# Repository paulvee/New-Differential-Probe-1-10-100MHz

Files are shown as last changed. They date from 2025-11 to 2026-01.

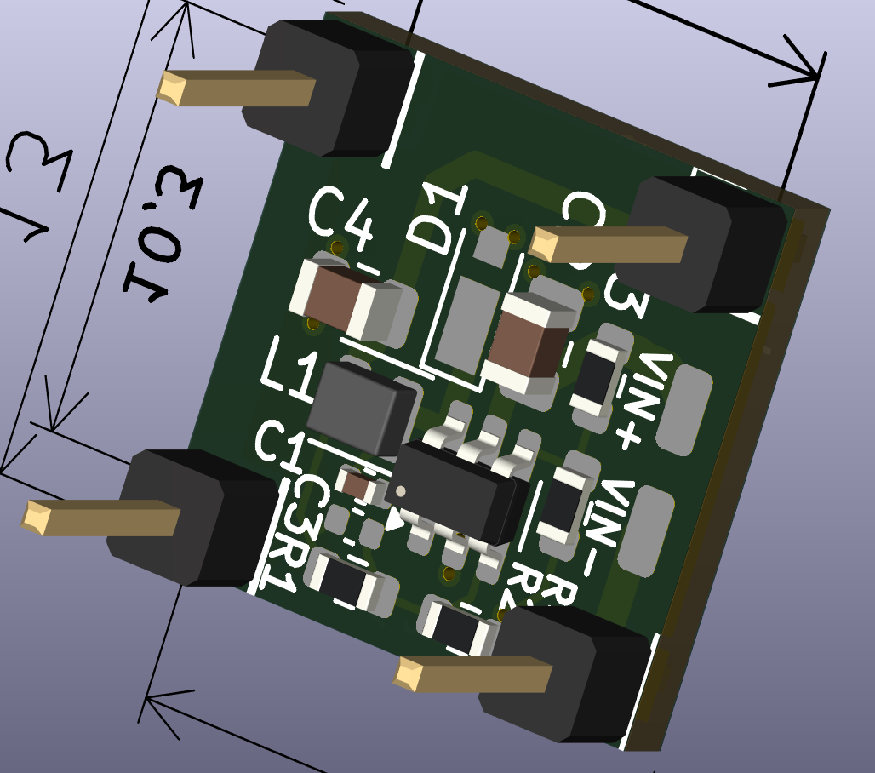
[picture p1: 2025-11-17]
VREG-BUCK-DB/3D profile.png

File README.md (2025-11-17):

This is a project to build a DIY differential probe for oscilloscopes (CRT or DSO)
This project was based on an earlier version of a few years ago and went through a number of enhancements based on what we learned.

There are now three versions of the probe, a 1MHz, a 10MHz and a 100MHz version, using the same PCB, but with different parts.
These three versions can be powered by a number of so called voltage regulator Daughter Boards.
Two are listed here. They can be powered by USB-C PD Trigger Boards. 

There is also a 3D printed version of the probe enclosure available.
The files in this project folder contain the schematics, the BOM and the production information to order the PCB's and enclosure.
All other information about this project can be found on my Blog here:
https://www.paulvdiyblogs.net/2025/08/building-new-100mhz-differential-probe.html

The specifications for the 100MHz probe are: (the others are on the Blog)
- Input impedance: 20MegOhm//1.25pF - differential, 10MegOhm//2.5pF for each terminal to GND.
- Differential Gain = 1/10V/V. Any lower than this and most hobby DSO's cannot resolve a 1V input signal with any clarity.
- Maximum AC Common Mode Voltage (with 50V differential input) = 350VAC
- CMRR > 90dB @ DC, ~60dB @ 1MHz.
- Differential Voltage Range > +/-25V for 240VAC common-mode, +/-25V for 0V common-mode.
- 3dB bandwidth >= 100MHZ (depends on signal amplitude)
- DC offset < 1mV (trimmed)
- Noise: 30mVpp or lower at output.
- Power supply: 5.25V +/- 0.25V. This can be a USB-C PD supply plus a regulator, see the power options.
- Cost: ~$50 not including shipping and handling costs. Not including 3D printed enclosure.

Enjoy building one of these, you will be happy that you did!

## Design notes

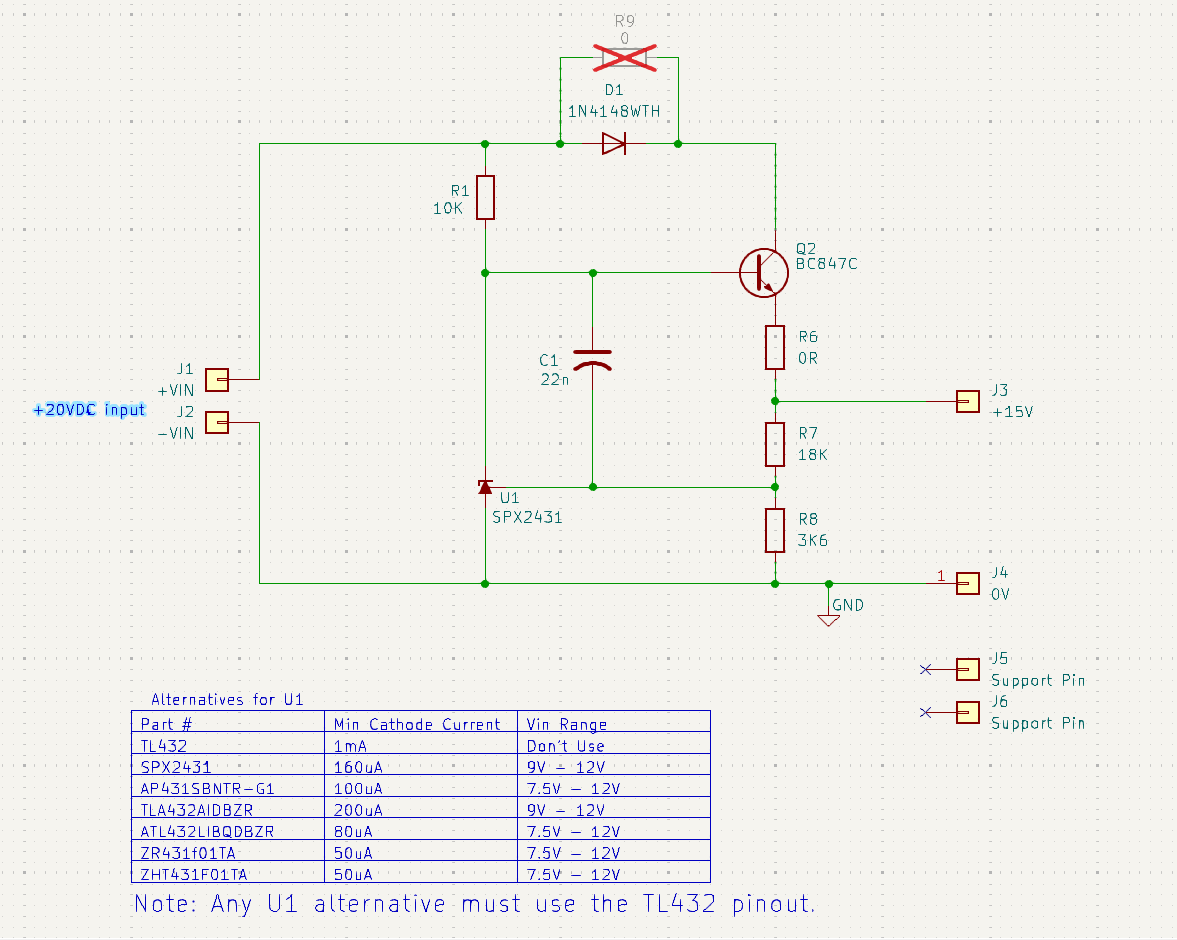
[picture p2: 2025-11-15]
VREG-DISCRETE-DB/Schematic 20V.png

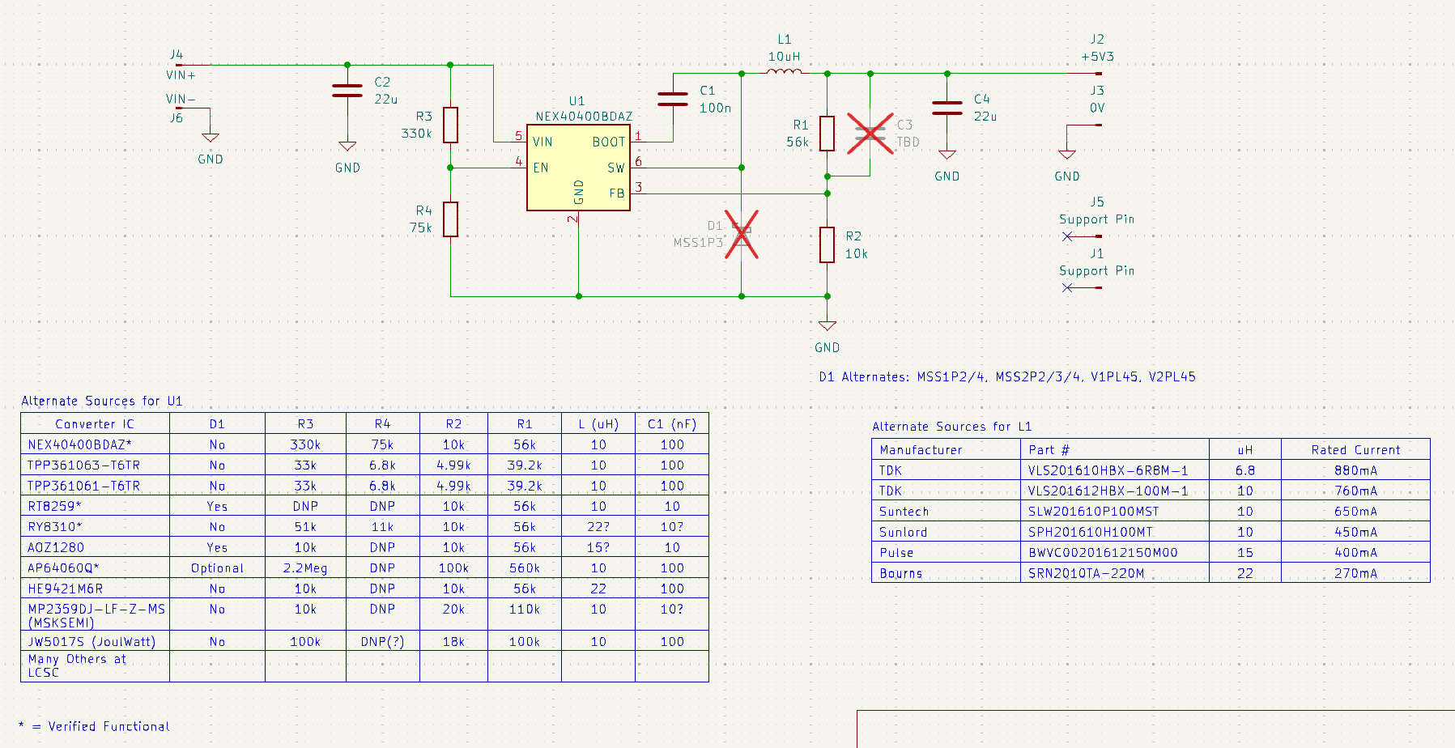
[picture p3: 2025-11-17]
VREG-BUCK-DB/Schematic.png

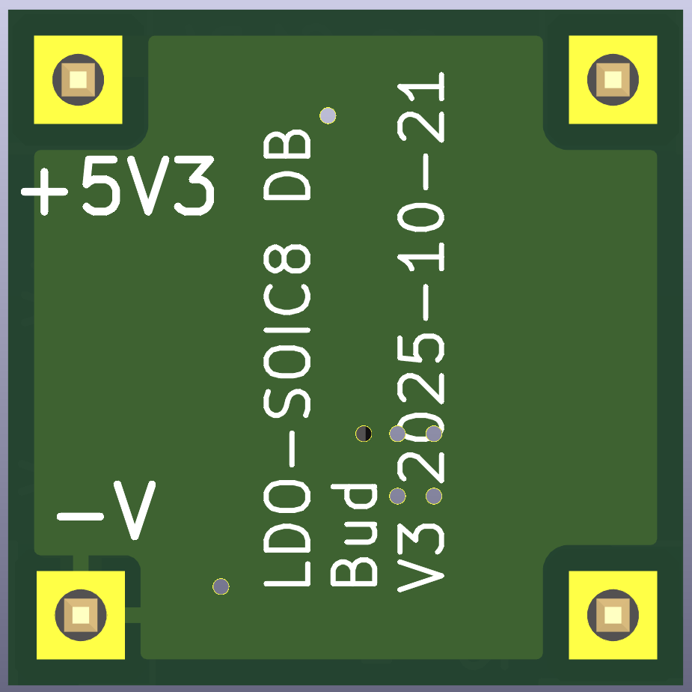
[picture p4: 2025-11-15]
VREG-SOIC8_DB/VREG-SOIC 3D top view.png

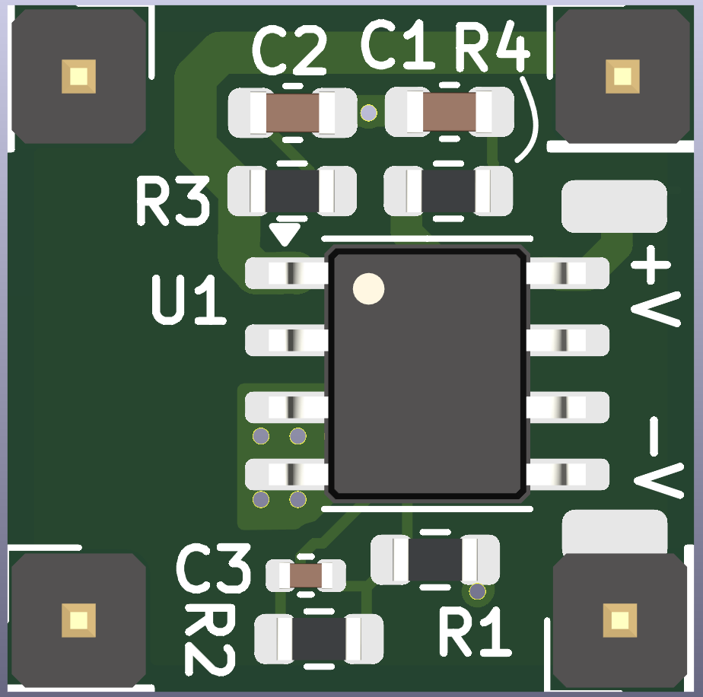
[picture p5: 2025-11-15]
VREG-SOIC8_DB/VREG-SOIC 3D view.png

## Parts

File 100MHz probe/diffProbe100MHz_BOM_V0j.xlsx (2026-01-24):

Reference | Value | Qty | Footprint | tempco | tolerance | Voltage | Source | Digikey Part # | LCSC Part # | LCSC Info
C1,C2,C3,C4,C5,C6,C7,C8 | 10p | 8 | Capacitor_SMD:C_0603_1608Metric | NPO | 1% | >200 | https://www.digikey.com/en/products/detail/kyocera-avx/KGQ15ACG2D100FT/1598981 | 478-KGQ15ACG2D100FTCT-ND | C2312027 | Double check the tolerance!
C9,C10 | 300p | 2 | Capacitor_SMD:C_0805_2012Metric | NPO | 1% | 50 | https://www.digikey.com/en/products/detail/kyocera-avx/08051A301FAT2A/1601047 | 478-10392-1-ND | C541567 | Double check the tolerance!
C11,C12 | 47p | 2 | Capacitor_SMD:C_0603_1608Metric | COG/NPO | 2% | 50 | https://www.digikey.com/en/products/detail/murata-electronics/GRM1885C1H470GA01D/2611190 | 490-11464-1-ND | C384994
C13,C14 | 220p | 2 | Capacitor_SMD:C_0805_2012Metric | COG/NPO | 1% | 50 | https://www.digikey.com/en/products/detail/yageo/CC0805FRNPO9BN221/5883936 | 311-4172-1-ND | C541563 | Double check the tolerance!
C15,C16 | 8-29p | 2 | My_Footprints:C_Trimmer_Voltronics_JR |  |  | 100 | https://www.digikey.com/en/products/detail/ew-electronics/sgc3s300/11689272 | 2447-SGC3S300CT-ND | C3273429 | Out of stock
C17,C18 *) | 0.2p | 2 | Capacitor_SMD:C_0402_1005Metric | COG/NPO | ±0.05p | 50 | https://www.digikey.com/en/products/detail/GJM1555C1HR20WB01D/490-11247-1-ND/5333087?itemSeq=313716339 | 490-11247-1-ND | Do not buy, they have a tolerance of 20%
C19,C21 *) | 0.4p | 2 | Capacitor_SMD:C_0402_1005Metric | COG/NPO | ±0.05p | 50 | https://www.digikey.com/en/products/detail/murata-electronics/GCM1555C1HR40WA16D/16033471 | 490-GCM1555C1HR40WA16DCT-ND | Do not buy, they have a tolerance of 20%
C20,C24,C26,C28 | 100p | 4 | Capacitor_SMD:C_0402_1005Metric | COG/NPO | 5% | 50 | https://www.digikey.com/en/products/detail/samsung-electro-mechanics/CL05C101JB5NNNC/3886683 | 1276-1025-1-ND | C1546 | Double check the tolerance!
C22,C25,C27,C29,C31 | 100n | 5 | Capacitor_SMD:C_0402_1005Metric | X7R | 10% | 50 | https://www.digikey.com/en/products/detail/kyocera-avx/KGM05CR71H104KH/6564238 | 478-KGM05CR71H104KHCT-ND | C307331
C23,C30,C36 | 4.7u | 3 | Capacitor_SMD:C_0603_1608Metric | X5R | 10% | 25 | https://www.digikey.com/en/products/detail/murata-electronics/GRM188R61E475KE11D/3900465 | 490-7203-1-ND | C69335
C32,C34 | 1u | 2 | Capacitor_SMD:C_0402_1005Metric | X5R | 10% | 16 | https://www.digikey.com/en/products/detail/murata-electronics/GRM155R61H105KE05D/13531808 | 490-GRM155R61H105KE05DCT-ND | C52923
C33,C35 | 10u | 2 | Capacitor_SMD:C_0603_1608Metric | X5R | 20% | 10 | https://www.digikey.nl/nl/products/detail/samsung-electro-mechanics/CL10A106KP8NNNC/3886850 | 1276-1192-1-ND | C19702
D1,D2 | BAV199 | 2 | Package_TO_SOT_SMD:SOT-23W |  |  |  | https://www.digikey.com/en/products/detail/diotec-semiconductor/BAV199/13164606 | 4878-BAV199CT-ND | C40919
D3 | LED | 1 | LED_SMD:LED_0603_1608Metric |  |  |  | https://www.digikey.nl/en/products/detail/harvatek-corporation/B19Y1TX-20P001713U1930/16602932? | 3147-B19Y1TX--20P001713U1930CT-ND | C2290
FB1,FB2 | FerriteBead | 2 | Inductor_SMD:L_0603_1608Metric |  | 1k@100MHz |  | https://www.digikey.com/en/products/detail/MPZ1608S102ATA00/445-8694-1-ND/3078632?itemSeq=313936277 | 445-MPZ1608S102ATA00CT-ND | C76814
J1 | SMA | 1 | Connector_Coaxial:SMA_Samtec_SMA-J-P-H-ST-EM1_EdgeMount |  |  |  | https://www.digikey.com/en/products/detail/samtec-inc/SMA-J-P-H-ST-EM1/2602450 | SAM8857-ND | C496550
J2 | 5.08 mm spacing pin header | 1 | My_Footprints:PinHeader_1x03_P2.54mm_Horizontal |  |  |  | https://www.digikey.nl/nl/products/detail/adam-tech/PH1RB-03-UA/9830403 | 2057-PH1RB-03-UA-ND | C3335189
J3 | -V | 1 | Connector_PinHeader_2.54mm:PinHeader_1x01_P2.54mm_Vertical |  |  |  | https://www.digikey.nl/nl/products/detail/adam-tech/PH1-01-UA/9830231 | 2057-PH1-01-UA-ND | C2932699
J4 | +V | 1 | Connector_PinHeader_2.54mm:PinHeader_1x01_P2.54mm_Vertical |  |  |  | https://www.digikey.nl/nl/products/detail/adam-tech/PH1-01-UA/9830231 | 2057-PH1-01-UA-ND | C2932699
J5,J6 | Support Pin | 2 | My_Footprints:TestPoint_THTPad_2.0x2.0mm_Drill1.0mm |  |  |  | https://www.digikey.nl/nl/products/detail/adam-tech/PH1-01-UA/9830232 | 2057-PH1-01-UA-ND | C2932699
R1,R2,R3,R4,R5,R6,R7,R8 | 2.49Meg | 8 | Resistor_SMD:R_0805_2012Metric |  | 1% | 150 | https://www.digikey.com/en/products/detail/yageo/RC0805FR-072M49L/727696 | 311-2.49MCRCT-ND | C83497 | Out of stock
R9,R11 | 36k | 2 | Resistor_SMD:R_0603_1608Metric |  | 1% |  | https://www.digikey.com/en/products/detail/koa-speer-electronics-inc/RN73H1JTTD3602F50/10674635 | 2019-RN73H1JTTD3602F50CT-ND | C136964
R10,R12 | 3k | 2 | Resistor_SMD:R_0603_1608Metric |  | 1% |  | https://www.digikey.com/en/products/detail/koa-speer-electronics-inc/RN73H1JTTD3001F100/10687131 | 2019-RN73H1JTTD3001F100CT-ND | C4211
R13,R14 | 1.5k | 2 | Resistor_SMD:R_0603_1608Metric |  | 1% |  | https://www.digikey.com/en/products/detail/koa-speer-electronics-inc/RN73H1JTTD1501F25/10686103 | 2019-RN73H1JTTD1501F25CT-ND | C114668
R15 | 412Ω | 1 | Resistor_SMD:R_0603_1608Metric |  | 1% |  | https://www.digikey.com/en/products/detail/yageo/RC0603FR-07412RL/727226 | 311-412HRCT-ND | C218022
R16,R17 | 3.92k | 2 | Resistor_SMD:R_0603_1608Metric |  | 1% |  | https://www.digikey.com/en/products/detail/yageo/RC0603FR-073K92L/727138 | RC0603FR-073K92L | C2933215
R18,R19 | 1.02k | 2 | Resistor_SMD:R_0603_1608Metric | 25ppm/C | 0.1% |  | https://www.digikey.nl/en/products/detail/yageo/RT0603BRD071K02L/1072313 | YAG2308CT-ND | C705734
R20,R21 | 1.27k | 2 | Resistor_SMD:R_0603_1608Metric | 25ppm/C | 0.1% |  | https://www.digikey.nl/en/products/detail/yageo/RT0603BRD071K27L/1072322 | YAG4492CT-ND | C855682
R22 | 51Ω | 1 | Resistor_SMD:R_0603_1608Metric |  | 1% |  | https://www.digikey.com/en/products/detail/yageo/RC0603FR-0751RL/727281 | 311-51.0HRCT-ND | C23197
R23 | 2.4k | 1 | Resistor_SMD:R_0603_1608Metric |  | 1% |  | https://www.digikey.com/en/products/detail/yageo/RC0603FR-132K4L/14008351 | 13-RC0603FR-132K4LCT-ND | C22940
R24,R29 | 10Ω | 2 | Resistor_SMD:R_0603_1608Metric |  | 1% |  | https://www.digikey.com/en/products/detail/yageo/RC0603FR-0710RL/726879 | 311-10.0HRCT-ND | C22859
R25,R28 | 510Ω | 2 | Resistor_SMD:R_0603_1608Metric |  | 1% |  | https://www.digikey.com/en/products/detail/yageo/RC0603FR-07510RL/727285 | 311-510HRCT-ND | C23193
R26,R27 | 10k | 2 | Resistor_SMD:R_0603_1608Metric |  | 1% |  | https://www.digikey.com/en/products/detail/yageo/RT0603FRE0710KL/1075040 | YAG2321CT-ND | C25804
R30,R31 | 1Ω | 2 | Resistor_SMD:R_0603_1608Metric |  | 5% |  | https://www.digikey.com/en/products/detail/yageo/RC0603JR-071RL/726676 | 311-1.0GRCT-ND | C22936
R32 | 3Ω | 1 | Resistor_SMD:R_0603_1608Metric |  | 5% |  | https://www.digikey.com/en/products/detail/yageo/RC0603JR-073RL/726753 | 311-3.0GRCT-ND | C23157
RV1,RV2 | 2k | 2 | Potentiometer_SMD:Potentiometer_Bourns_3224J_Horizontal |  | 20% |  | https://www.digikey.com/en/products/detail/bourns-inc/TC33X-2-202E/612860 | TC33X-202ECT-ND | C720647
U1 | LTC6269xMS8E-10 | 1 | Package_SO:MSOP-8-1EP_3x3mm_P0.65mm_EP1.68x1.88mm |  |  |  | https://www.digikey.com/en/products/detail/analog-devices-inc/LTC6269IMS8E-10-PBF/5253547 | 505-LTC6269IMS8E-10#PBF-ND | C689183
U2 | LTC6268xS6 | 1 | Package_TO_SOT_SMD:TSOT-23-6 |  |  |  | https://www.digikey.com/en/products/detail/analog-devices-inc/LTC6268IS6-TRMPBF/5030349 | 505-LTC6268IS6#TRMPBFCT-ND | C580981
U4 | LM7301DBV | 1 | Package_TO_SOT_SMD:SOT-23-5 |  |  |  | https://www.digikey.com/en/products/detail/texas-instruments/LM7301IM5X-NOPB/367325 | LM7301IM5X/NOPBCT-ND | C468181
Alternative tuning caps for C11, C12
 | 33p | 2 | Capacitor_SMD:C_0603_1608Metric | NPO | 1% | 50 | https://www.digikey.nl/nl/products/detail/cal-chip-electronics-inc/CHV0603N250390FCT/22155351 | CHV0603N250390FCT | C527048
 | 39p | 2 | Capacitor_SMD:C_0603_1608Metric | NPO | 1% | 50 | https://www.digikey.nl/nl/products/detail/kyocera-avx/KGM15ACG1H560FT/1599894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 | KGM15ACG1H560FT | C527049
 | 47p | 2 | Capacitor_SMD:C_0603_1608Metric | NPO | 1% | 50 | https://www.digikey.com/en/products/detail/murata-electronics/GRM1885C1H470GA01D/2611190 | 490-11464-1-ND | C3909655
 | 56p | 2 | Capacitor_SMD:C_0603_1608Metric | NPO | 1% | 50 | https://www.digikey.nl/nl/products/detail/kyocera-avx/KGM15ACG1H560FT/1599894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 | KGM15ACG1H560FT | C527049
 | 68p | 2 | Capacitor_SMD:C_0603_1608Metric | NPO | 1% | 50 | any mfg will do
 | 82p | 2 | Capacitor_SMD:C_0603_1608Metric | NPO | 1% | 50 | any mfg will do
 | 100p | 2 | Capacitor_SMD:C_0603_1608Metric | NPO | 1% | 50 | any mfg will do
Alternative parts
RV1, RV2 | 2k | 2 | Potentiometer_Bourns_3314J_Horizontal | 20% |  |  | https://www.digikey.com/en/products/detail/bourns-inc/3314J-2-202E/2536163 | 3314J-2-202ECT-ND | C720647
Note
 | The Digikey part numbers are the reference parts.
 | If you want to search at other lists, use the manufacturing part number listed on the Digikey page.
 | Using the Digikey part number may give you incorrect results.
 | The LCSC partnumbers are suggestions and not always a direct replacement.
 | As an example, the part may have the same specifications, but manufacturer may be different.
 | Be aware of the size, the tolerance, voltage, tempco or ppm/C differences.
Recommendations: *)
 | Obtain C17, C18, C19 and C21 from Digikey based on our problems experienced with the LCSC supplied parts.
Updates
C33,C35 |  |  | Updated DigiKey p/n. LCSC p/n was correct
R16,R17 |  |  | Updated DigiKey p/n. LCSC p/n was correct
C11,C12 |  |  | Updated DigiKey p/n. LCSC p/n was correct

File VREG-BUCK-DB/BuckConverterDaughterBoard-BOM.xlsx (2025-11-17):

 | References | Value | Footprint | Tolerance | Rating | Source | Digikey Part # | LCSC Part # | Quantity
1 | C2, C4 | 22u | C_0805_2012Metric | 20% | 25V, X5R | https://www.digikey.com/en/products/detail/samsung-electro-mechanics/CL21A226MAYNNNE/10479857 | 1276-CL21A226MAYNNNECT-ND | C45783 | 2
2 | C1 | 100n | C_0402_1005Metric | 10% | 50V, X7R | https://www.digikey.com/en/products/detail/kyocera-avx/KGM05CR71H104KH/6564238 | 478-KGM05CR71H104KHCT-ND | C307331 | 1
3 | C3 | TBD | C_0402_1005Metric | 10% | 50V, X7R | https://www.digikey.com/en/products/detail/kyocera-avx/KGM05CR71H104KH/6564238 | 478-KGM05CR71H104KHCT-ND | C307331 | 1
4 | R1 | 56k | R_0603_1608Metric | 1% |  | https://www.digikey.com/en/products/detail/yageo/RC0603FR-0756KL/2827626 | 311-56KHRCT-ND | C23206 | 1
5 | R2 | 10k | R_0603_1608Metric | 1% |  | https://www.digikey.com/en/products/detail/yageo/RT0603FRE0710KL/1075040 | YAG2321CT-ND | C25804 | 1
6 | R3 | 330k | R_0603_1608Metric | 1% |  | https://www.digikey.com/en/products/detail/yageo/RC0603FR-10330KL/14008341 | 13-RC0603FR-10330KLCT-ND | C23137 | 1
7 | R4 | 75k | R_0603_1608Metric | 1% |  | https://www.digikey.com/en/products/detail/yageo/AC0603FR-0775KL/5896284 | YAG3629CT-ND | C23242 | 1
8 | L1 | 10uH | L_Wuerth_MAPI-2010 | 20% | 450mA | https://www.digikey.com/en/products/detail/shenzhen-sunlord-electronics-co-ltd/SPH201610H100MT/14120481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 | 3442-SPH201610H100MTCT-ND | C96784 | 1
9 | D1 | MSS1P3 | D_MicroSMP_AK |  |  | https://www.digikey.com/en/products/detail/vishay-general-semiconductor-diodes-division/MSS1P3L-M3-89A/2071752 | MSS1P3L-M3/89AGICT-ND | C5125027 | 1
10 | U1 | NEX40400BDAZ | SOT-23-6 |  |  | https://www.digikey.com/en/products/detail/nexperia-usa-inc/NEX40400BDAZ/25978251 | 1727-NEX40400BDAZCT-ND | C370876 | 1
11 | J1, J5 | Support Pin | PinHeader_1x01_P2.54mm_Vertical |  |  | https://www.digikey.nl/nl/products/detail/adam-tech/PH1-01-UA/9830231 | 2057-PH1-01-UA-ND | C2932699 | 2
12 | J2 | +5V3 | PinHeader_1x01_P2.54mm_Vertical |  |  | https://www.digikey.nl/nl/products/detail/adam-tech/PH1-01-UA/9830231 | 2057-PH1-01-UA-ND | C2932699 | 1
13 | J3 | 0V | PinHeader_1x01_P2.54mm_Vertical |  |  | https://www.digikey.nl/nl/products/detail/adam-tech/PH1-01-UA/9830231 | 2057-PH1-01-UA-ND | C2932699 | 1

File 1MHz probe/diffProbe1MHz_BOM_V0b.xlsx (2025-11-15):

References | Value | Qty | Footprint | tolerance | Voltage | tempco | Source | Digikey Part # | LCSC Part # | LCSC Info
C1, C2, C3, C4, C5, C6, C7, C8 | 20p | 8 | C_0603_1608Metric | 1% | >200V | NPO | https://www.digikey.nl/en/products/detail/vishay-vitramon/VJ0603D200FXPAJ/5095340 | 720-VJ0603D200FXPAJCT-ND | C2409788, C2409793 | Out of stock
C9, C10, C13, C14 | 220p | 4 | C_0805_2012Metric | 1% | 50V | COG/NPO | https://www.digikey.com/en/products/detail/yageo/CC0805FRNPO9BN221/5883936 | 311-4172-1-ND | C541563
C11, C12 | 30p | 2 | C_0603_1608Metric | 5% | 50V | COG/NPO | https://www.digikey.com/en/products/detail/stackpole-electronics-inc/CML0603C0G300JT50V/10659967 | 738-CML0603C0G300JT50VCT-ND | C1658
C15, C16 | 8-29p | 2 | C_Trimmer_Voltronics_JR |  |  |  | https://www.digikey.com/en/products/detail/ew-electronics/SGC3S300NM/11689290 | 2447-SGC3S300NMCT-ND | C3273429
C17, C18 | 10p | 2 | C_0402_1005Metric | 10% | 50V | COG/NPO | https://www.digikey.com/en/products/detail/yageo/CC0402JRNPO9BN100/302748 | 311-1014-1-ND | C32949
C19, C21 | 82p | 2 | C_0402_1005Metric | 5% | 50V | COG/NPO | https://www.digikey.com/en/products/detail/yageo/CC0402JPNPO9BN820/11490338 | 13-CC0402JPNPO9BN820CT-ND | C45501
C20, C24, C26, C28 | 10n | 4 | C_0402_1005Metric | 10% | 50V | X7R | https://www.digikey.com/en/products/detail/kemet/C0402C103K5RACTU/501968 | 399-C0402C103K5RACTUCT-ND | C15195
C22, C25, C27, C29, C31 | 100n | 5 | C_0402_1005Metric | 10% | 50V | X7R | https://www.digikey.com/en/products/detail/kyocera-avx/KGM05CR71H104KH/6564238 | 478-KGM05CR71H104KHCT-ND | C307331
C23, C30, C33 | 2.2u | 3 | C_0603_1608Metric | 10% | 35V | X5R | https://www.digikey.nl/en/products/detail/murata-electronics/GRM188R61H225KE11D/4905363 | GRM188R61H225KE11D | C77047
C32, C34 | 1u | 2 | C_0402_1005Metric | 10% | 50V | X5R | https://www.digikey.com/en/products/detail/murata-electronics/GRM155R61H105KE05D/13531808 | 490-GRM155R61H105KE05DCT-ND | C52923
C35, C36 | 4.7u | 2 | C_0603_1608Metric | 10% | 25V | X5R | https://www.digikey.com/en/products/detail/murata-electronics/GRM188R61E475KE11D/3900465 | 490-7203-1-ND | C19666
D1, D2 | BAV199 | 2 | SOT-23W |  |  |  | https://www.digikey.com/en/products/detail/diotec-semiconductor/BAV199/13164606 | 4878-BAV199CT-ND | C40919
D3 | LED | 1 | LED_0603_1608Metric |  |  |  | https://www.digikey.nl/en/products/detail/harvatek-corporation/B19Y1TX-20P001713U1930/16602932? | 3147-B19Y1TX--20P001713U1930CT-ND | C2290
FB1, FB2 | FerriteBead | 2 | L_0603_1608Metric |  |  |  | https://www.digikey.com/en/products/detail/MPZ1608S102ATA00/445-8694-1-ND/3078632?itemSeq=313936277 | 445-MPZ1608S102ATA00CT-ND | C76814
J1 | SMA | 1 | SMA_Samtec_SMA-J-P-H-ST-EM1_EdgeMount |  |  |  | https://www.digikey.com/en/products/detail/samtec-inc/SMA-J-P-H-ST-EM1/2602450 | SAM8857-ND | C496550
J2 | 5.08 mm spacing pin header | 1 | PinHeader_1x03_P2.54mm_Horizontal |  |  |  | https://www.digikey.nl/nl/products/detail/adam-tech/PH1RB-03-UA/9830403 | 2057-PH1RB-03-UA-ND | C3335189
J3 | V+ | 1 | PinHeader_1x01_P2.54mm_Vertical |  |  |  | https://www.digikey.nl/nl/products/detail/adam-tech/PH1-01-UA/9830231 | 2057-PH1-01-UA-ND | C2932699
J4 | V- | 1 | PinHeader_1x01_P2.54mm_Vertical |  |  |  | https://www.digikey.nl/nl/products/detail/adam-tech/PH1-01-UA/9830231 | 2057-PH1-01-UA-ND | C2932699
J5, J6 | Support Pin | 2 | TestPoint_THTPad_2.0x2.0mm_Drill1.0mm |  |  |  | https://www.digikey.nl/nl/products/detail/adam-tech/PH1-01-UA/9830231 | 2057-PH1-01-UA-ND | C2932699
R1, R2, R3, R4, R5, R6, R7, R8 | 1.24Meg | 8 | R_0805_2012Metric | 1% | 150V |  | https://www.digikey.com/en/products/detail/yageo/RC0805FR-071M24L/727473 | 311-1.24MCRCT-ND | C409955
R9, R11 | 47.5k | 2 | R_0603_1608Metric | 1% |  |  | https://www.digikey.com/en/products/detail/yageo/RC0603FR-0747K5L/727255 | 311-47.5KHRCT-ND | C23061
R10, R12 | 1.6k | 2 | R_0603_1608Metric | 1% |  |  | https://www.digikey.com/en/products/detail/bourns-inc/CR0603-FX-1601ELF/3783762 | CR0603-FX-1601ELFCT-ND | C22847
R13, R14 | 22R | 2 | R_0603_1608Metric | 1% |  |  | https://www.digikey.com/en/products/detail/yageo/RC0603FR-0722RL/727055 | 311-22.0HRCT-ND | C23345
R15 | 430R | 1 | R_0603_1608Metric | 1% |  |  | https://www.digikey.com/en/products/detail/yageo/RC0603FR-07430RL/727236 | 311-430HRCT-ND | C218022
R16, R17 | 1.5k | 2 | R_0603_1608Metric | 1% |  |  | https://www.digikey.com/en/products/detail/stackpole-electronics-inc/RMCF0603FT1K50/1761186 | RMCF0603FT1K50CT-ND | C22843
R18, R19 | 1.02k | 2 | R_0603_1608Metric | 0.1% |  | 25ppm/C | https://www.digikey.com/en/products/detail/panasonic-electronic-components/ERA-3AEB1021V/2026749 | P1.02KDBCT-ND | C4070321, C705734
R20 | 1.21k | 1 | R_0603_1608Metric | 0.1% |  | 25ppm/C | https://www.digikey.com/en/products/detail/panasonic-electronic-components/ERA-3AEB1211V/2026755 | P1.21KDBCT-ND | C2076348, C705737
R21 | 1.27k | 1 | R_0603_1608Metric | 0.1% |  | 25ppm/C | https://www.digikey.com/en/products/detail/panasonic-electronic-components/ERA-3AEB1271V/2026757 | P1.27KDBCT-ND | C2074631, C855682
R22 | 51R | 1 | R_0603_1608Metric | 1% |  |  | https://www.digikey.com/en/products/detail/yageo/RC0603FR-0751RL/727281 | 311-51.0HRCT-ND | C23197
R23 | 12k | 1 | R_0603_1608Metric | 1% |  |  | https://www.digikey.com/en/products/detail/stackpole-electronics-inc/RMCF0603FT12K0/1761297 | RMCF0603FT12K0CT-ND | C22790
R24 | 62R | 1 | R_0603_1608Metric | 1% |  |  | https://www.digikey.com/en/products/detail/stackpole-electronics-inc/RMCF0603FT62R0/1760778 | RMCF0603FT62R0CT-ND | C23222
R25, R28 | 3k | 2 | R_0603_1608Metric | 1% |  |  | https://www.digikey.com/en/products/detail/rohm-semiconductor/MCR03SEQPF3001/26824872 | 846-MCR03SEQPF3001CT-ND | C4211
R26, R27 | 10k | 2 | R_0603_1608Metric | 1% |  |  | https://www.digikey.nl/en/products/detail/stackpole-electronics-inc/RMCF0603FT10K0/1761235 | RMCF0603FT10K0CT-ND | C25804
R29 | 1.02k | 1 | R_0603_1608Metric | 1% |  |  | https://www.digikey.com/en/products/detail/panasonic-electronic-components/ERA-3AEB1021V/2026749 | P1.02KDBCT-ND | C705734 |  | 1% required, but used same part as R18, R19
R30, R31 | 1R | 2 | R_0603_1608Metric | 5% |  |  | https://www.digikey.nl/en/products/detail/yageo/RC0603JR-071RL/726676 | 311-1.0GRCT-ND | C22936
R32 | 3R | 1 | R_0603_1608Metric | 5% |  |  | https://www.digikey.com/en/products/detail/yageo/RC0603JR-073RL/726753 | 311-3.0GRCT-ND | C185299, C23157
RV1, RV2 | 2k | 2 | Potentiometer_Bourns_3224J_Horizontal | 20% |  |  | https://www.digikey.com/en/products/detail/bourns-inc/TC33X-2-202E/612860 | TC33X-202ECT-ND | C720647
U1 | OPA2810IDGKR | 1 | MSOP-8-1EP_3x3mm_P0.65mm_EP1.68x1.88mm |  |  |  | https://www.digikey.com/en/products/detail/texas-instruments/OPA2810IDGKR/9489204 | 296-50210-1-ND | C2864204
U2 | OPA810IDBVR | 1 | SOT-23-5 |  |  |  | https://www.digikey.com/en/products/detail/texas-instruments/OPA810IDBVR/15856819 | 296-OPA810IDBVRCT-ND | C2833513
U4 | LM7301DBV | 1 | SOT-23-5 |  |  |  | https://www.digikey.com/en/products/detail/texas-instruments/LM7301IM5X-NOPB/367325 | LM7301IM5X/NOPBCT-ND | C468181
Alternative parts |  | Alternative parts
RV1, RV2 | 2k | 1 | Potentiometer_Bourns_3314J_Horizontal | 20% |  |  | https://www.digikey.com/en/products/detail/bourns-inc/3314J-2-202E/2536163 | 3314J-2-202ECT-ND | C6083393
Note
 | The Digikey part numbers are the reference parts.
 | If you want to search at other lists, use the manufacturing part number listed on the Digikey page.
 | Using the Digikey part number may give you incorrect results.
 | The LCSC partnumbers are suggestions and not always a direct replacement.
 | As an example, the part may have the same specifications, but manufacturer may be different.
 | Be aware of the size, the tolerance, voltage, tempco or ppm/C differences.

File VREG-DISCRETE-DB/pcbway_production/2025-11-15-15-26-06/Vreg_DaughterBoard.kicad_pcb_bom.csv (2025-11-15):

Designator | Quantity | Value | Footprint | Package | MPN | DNP | Mount_Type | Description | source | tolerance | Price | Voltage/Wattage | LCSC Part # | Rating | Digikey Part # | Sim.Device | Sim.Pins
C1 | 1 | 22n | C_0402_1005Metric |  |  |  | smt | capacitor, US symbol | https://www.digikey.com/en/products/detail/kemet/C0402C223K5RACTU/2196486 | 10% | .1 | 50V X7R | C1532 | 50V X7R | 399-C0402C223K5RACTUCT-ND
D1 | 1 | 1N4148WTH | D_SOD-523 |  |  |  | smt | 75V 0.15A Fast switching Diode, SOD-523 | https://www.digikey.com/en/products/detail/taiwan-semiconductor-corporation/1N4148WTH-RSG/26257460 |  |  |  | C917006 |  | 1801-1N4148WTHRSGCT-ND | D | 1=K 2=A
J3 | 1 | +Vout | PinHeader_1x01_P2.54mm_Vertical |  |  |  | tht | Generic connector, single row, 01x01, script generated (kicad-library-utils/schlib/autogen/connector/) | https://www.digikey.nl/nl/products/detail/adam-tech/PH1-01-UA/9830231 |  |  |  | C2932699 |  | 2057-PH1-01-UA-ND
J4 | 1 | 0V | PinHeader_1x01_P2.54mm_Vertical |  |  |  | tht | Generic connector, single row, 01x01, script generated (kicad-library-utils/schlib/autogen/connector/) | https://www.digikey.nl/nl/products/detail/adam-tech/PH1-01-UA/9830231 |  |  |  | C2932699 |  | 2057-PH1-01-UA-ND
J5, J6 | 2 | Support Pin | PinHeader_1x01_P2.54mm_Vertical |  |  |  | tht | Generic connector, single row, 01x01, script generated (kicad-library-utils/schlib/autogen/connector/) | https://www.digikey.nl/nl/products/detail/adam-tech/PH1-01-UA/9830231 |  |  |  | C2932699 |  | 2057-PH1-01-UA-ND
Q1, Q2 | 2 | BC847C | SOT-23 |  |  |  | smt | 0.1A Ic, 45V Vce, NPN Transistor, SOT-23 | https://www.digikey.com/en/products/detail/onsemi/BC847CLT3G/1476015 |  | .11 | 45 | C8664 | 45V | BC847CLT3GOSCT-ND
R1, R4, R8 | 3 | 4.99k | R_0603_1608Metric |  |  |  | smt | Resistor | https://www.digikey.com/en/products/detail/yageo/RC0603FR-134K99L/17013367 | 1% | .1 | 100mW | C23046 | 100mW | 13-RC0603FR-134K99LCT-ND
R2 | 1 | 43k | R_0603_1608Metric |  |  | Yes | smt | Resistor | https://www.digikey.com/en/products/detail/yageo/RC0603FR-0743KL/727233 | 1% | .1 |  | C23172 |  | 311-43.0KHRCT-ND
R3 | 1 | 10k | R_0603_1608Metric |  |  | Yes | smt | Resistor | https://www.digikey.com/en/products/detail/yageo/RT0603FRE0710KL/1075040 | 1% | .1 |  | C25804 |  | YAG2321CT-ND
R5, R6 | 2 | 2.0 | R_0603_1608Metric |  |  |  | smt | Resistor | https://www.digikey.com/en/products/detail/yageo/RC0603JR-072RL/5918445 | 5% | .1 |  | C22977 |  | 13-RC0603JR-072RLCT-ND
R7 | 1 | 5.6k | R_0603_1608Metric |  |  |  | smt | Resistor | https://www.digikey.com/en/products/detail/yageo/RC0603FR-075K6L/727275 | 1% | .1 |  | C23189 |  | 311-5.60KHRCT-ND
U1 | 1 | SPX2431 | SOT-23 |  |  |  | smt | Shunt Regulator, SOT-23 | https://www.digikey.com/en/products/detail/texas-instruments/TL431AIDBZR/686856 | 1% | 0.25 |  | C94430 |  | 296-17329-1-ND
U2 | 1 | SPX2431 | SOT-23 |  |  | Yes | smt | Shunt Regulator, SOT-23 | https://www.digikey.com/en/products/detail/texas-instruments/TL431AIDBZR/686856 | 1% | 0.25 |  | C94430 |  | 296-17329-1-ND

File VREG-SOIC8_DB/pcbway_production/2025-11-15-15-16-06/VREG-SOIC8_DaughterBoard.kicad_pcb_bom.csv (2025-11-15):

Designator | Quantity | Value | Footprint | Package | MPN | DNP | Mount_Type | Description | Voltage/Wattage | tolerance | LCSC Part # | Digikey Part # | source
C1, C2 | 2 | 4.7u | C_0603_1608Metric |  |  |  | smt | Unpolarized capacitor | 35V X7R/X5R | 10% | C19666 | 490-7205-1-ND | [C1]https://www.digikey.com/en/products/detail/murata-electronics/GRM188R6YA475KE15D/3900468; [C2]https://www.digikey.com/en/products/detail/murata-electronics/GRM188R61E475KE11D/3900465
C3 | 1 | 1n | C_0402_1005Metric |  |  |  | smt | Unpolarized capacitor | 50V X7R/X5R | 10% | C1523 | 490-1303-1-ND | https://www.digikey.com/en/products/detail/murata-electronics/GRM155R71H102KA01D/587225
J3 | 1 | +5V3 | PinHeader_1x01_P2.54mm_Vertical |  |  |  | tht | Generic connector, single row, 01x01, script generated (kicad-library-utils/schlib/autogen/connector/) |  |  | C2932699 | 2057-PH1-01-UA-ND | https://www.digikey.nl/nl/products/detail/adam-tech/PH1-01-UA/9830231
J4 | 1 | -V | PinHeader_1x01_P2.54mm_Vertical |  |  |  | tht | Generic connector, single row, 01x01, script generated (kicad-library-utils/schlib/autogen/connector/) |  |  | C2932699 | 2057-PH1-01-UA-ND | https://www.digikey.nl/nl/products/detail/adam-tech/PH1-01-UA/9830231
J5, J6 | 2 | Support Pin | PinHeader_1x01_P2.54mm_Vertical |  |  |  | tht | Generic connector, single row, 01x01, script generated (kicad-library-utils/schlib/autogen/connector/) |  |  | C2932699 | 2057-PH1-01-UA-ND | https://www.digikey.nl/nl/products/detail/adam-tech/PH1-01-UA/9830231
R1 | 1 | 10k | R_0603_1608Metric |  |  |  | smt | Resistor |  | 1% | C25804 | YAG2321CT-ND | https://www.digikey.com/en/products/detail/yageo/RT0603FRE0710KL/1075040
R2 | 1 | 33k | R_0603_1608Metric |  |  |  | smt | Resistor |  | 1% | C4216 | 311-33.0KHRCT-ND | https://www.digikey.com/en/products/detail/yageo/RC0603FR-0733KL/727159
R3 | 1 | 1Ω | R_0603_1608Metric |  |  |  | smt | Resistor |  | 5% | C22936 | 311-1.0GRCT-ND | https://www.digikey.com/en/products/detail/yageo/RC0603JR-071RL/726676
R4 | 1 | 3Ω | R_0603_1608Metric |  |  |  | smt | Resistor |  | 5% | C23157 | 311-1.0GRCT-ND | https://www.digikey.com/en/products/detail/yageo/RC0603JR-073RL/726753
U1 | 1 | LP2951CDR2G | SOIC-8_3.9x4.9mm_P1.27mm |  |  |  | smt | Micropower Voltage Regulators with Shutdown, 100mA, Fixed Output 5.0V, LDO, SOIC-8 |  | 0.5% | C7987 | LP2951ACDR2GOSCT-ND | https://www.digikey.com/en/products/detail/onsemi/LP2951ACDR2G/918534

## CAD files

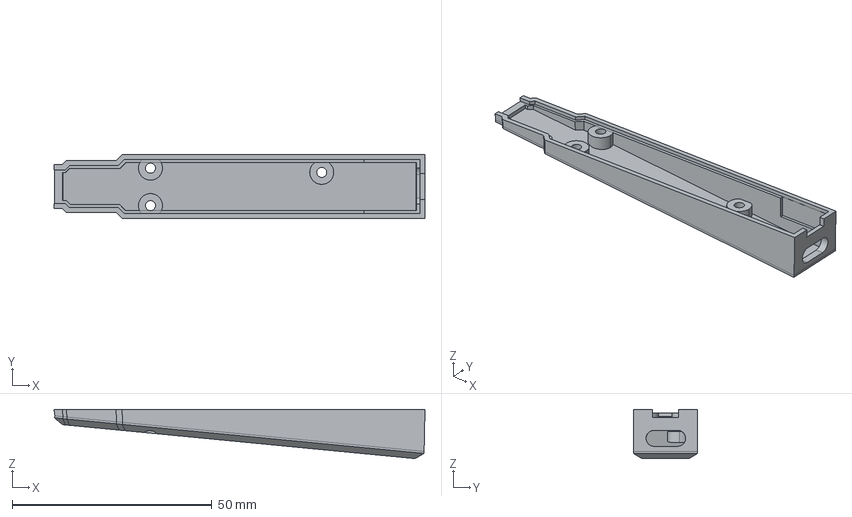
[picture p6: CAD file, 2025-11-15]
diffProbeCase/DiffProbeSlim-ProbeHousing.step
92.8 x 16.1 x 12.3 mm

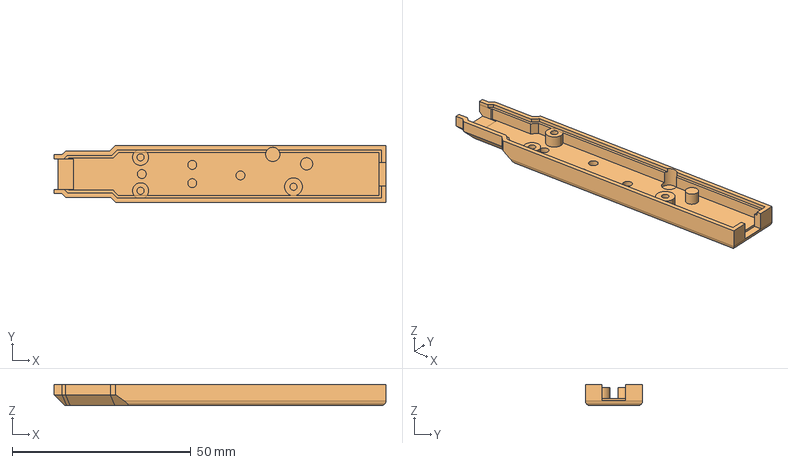
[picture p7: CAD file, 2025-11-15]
diffProbeCase/DiffProbeSlim-ProbeLid.step
92.8 x 16.0 x 5.90 mm
PlusMinus
CM ADJ
Compensation
OFFSET
10X

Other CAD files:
diffProbeCase/DiffProbeSlim-ProbeHousing.stl
diffProbeCase/DiffProbeSlim-ProbeLid.stl

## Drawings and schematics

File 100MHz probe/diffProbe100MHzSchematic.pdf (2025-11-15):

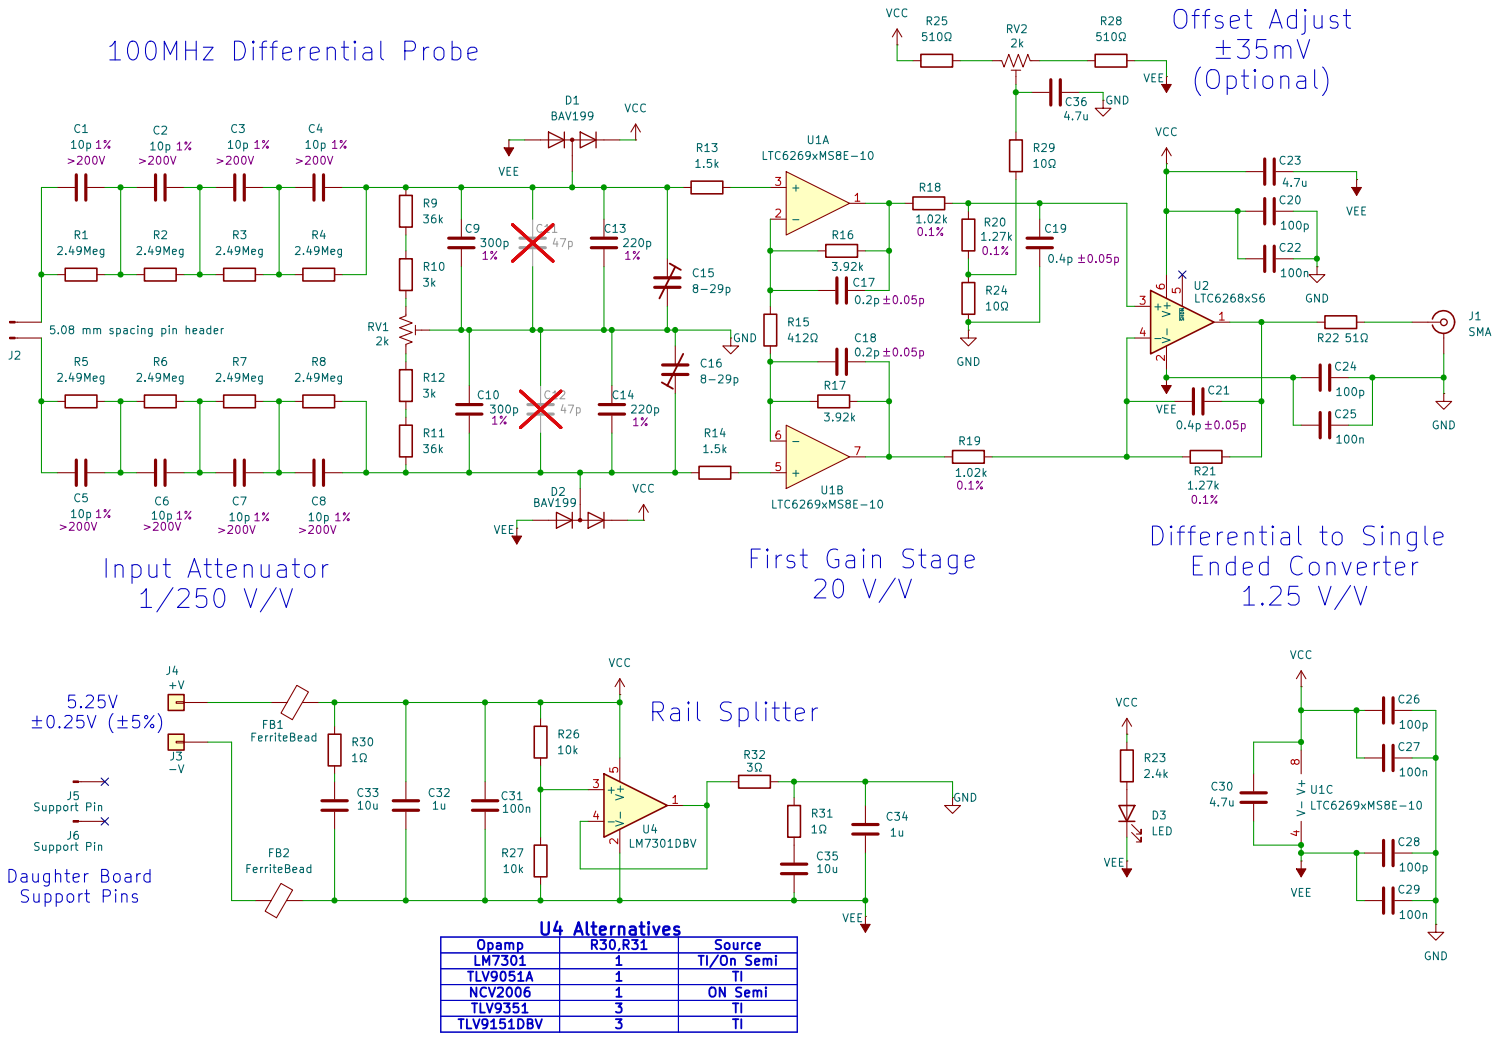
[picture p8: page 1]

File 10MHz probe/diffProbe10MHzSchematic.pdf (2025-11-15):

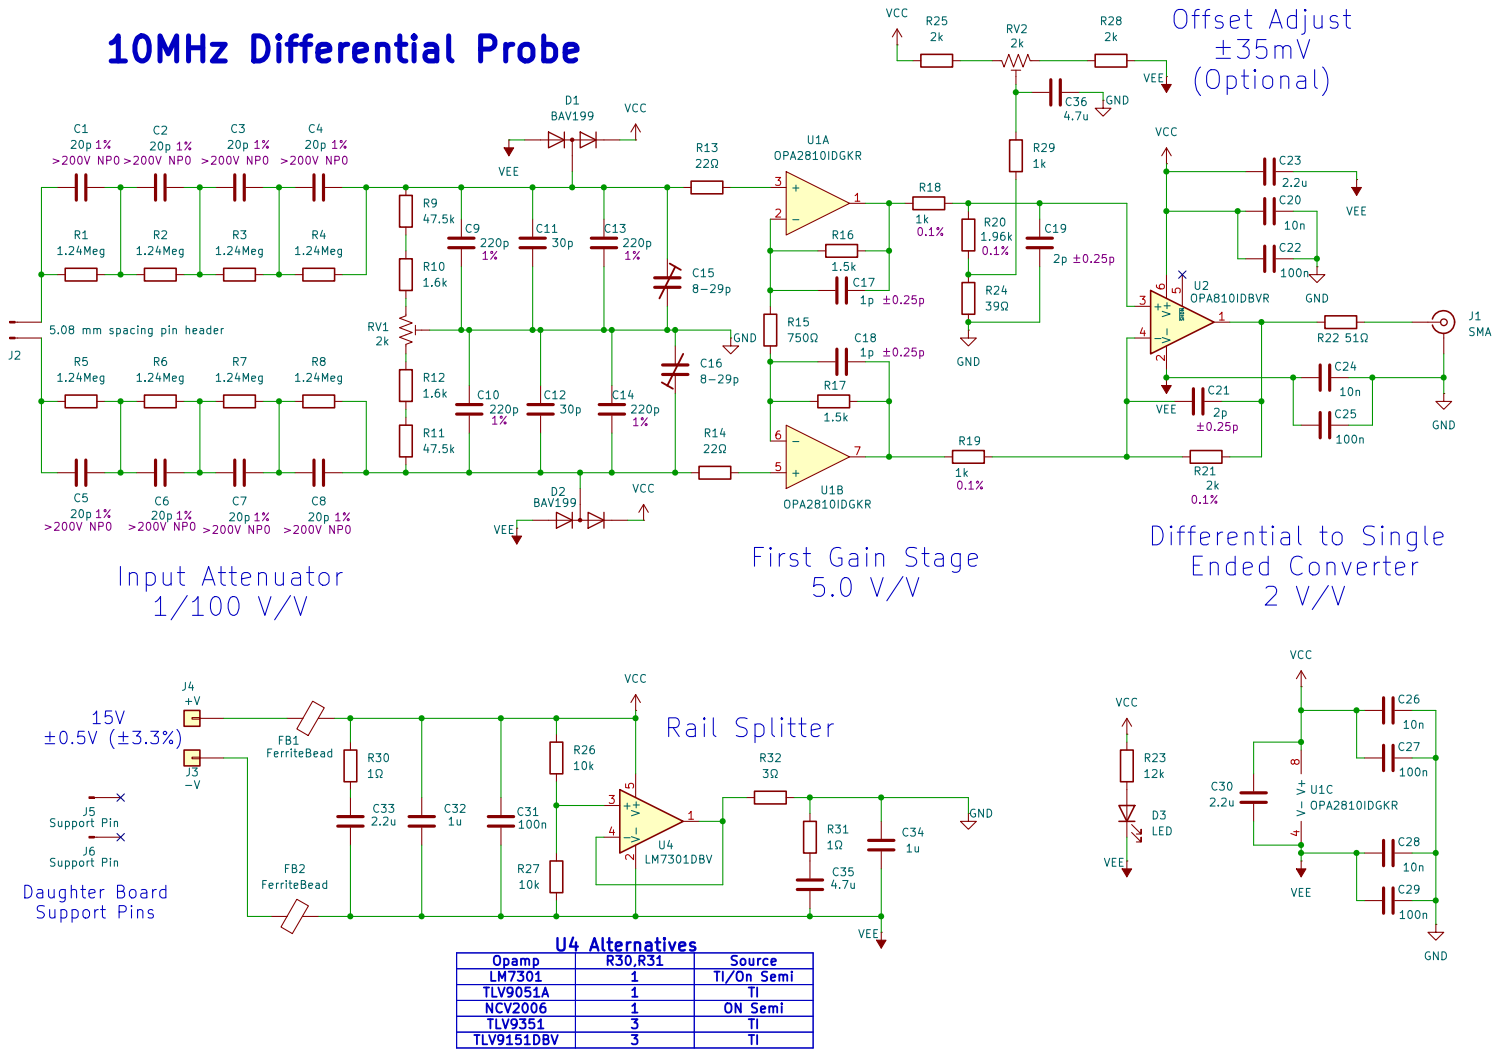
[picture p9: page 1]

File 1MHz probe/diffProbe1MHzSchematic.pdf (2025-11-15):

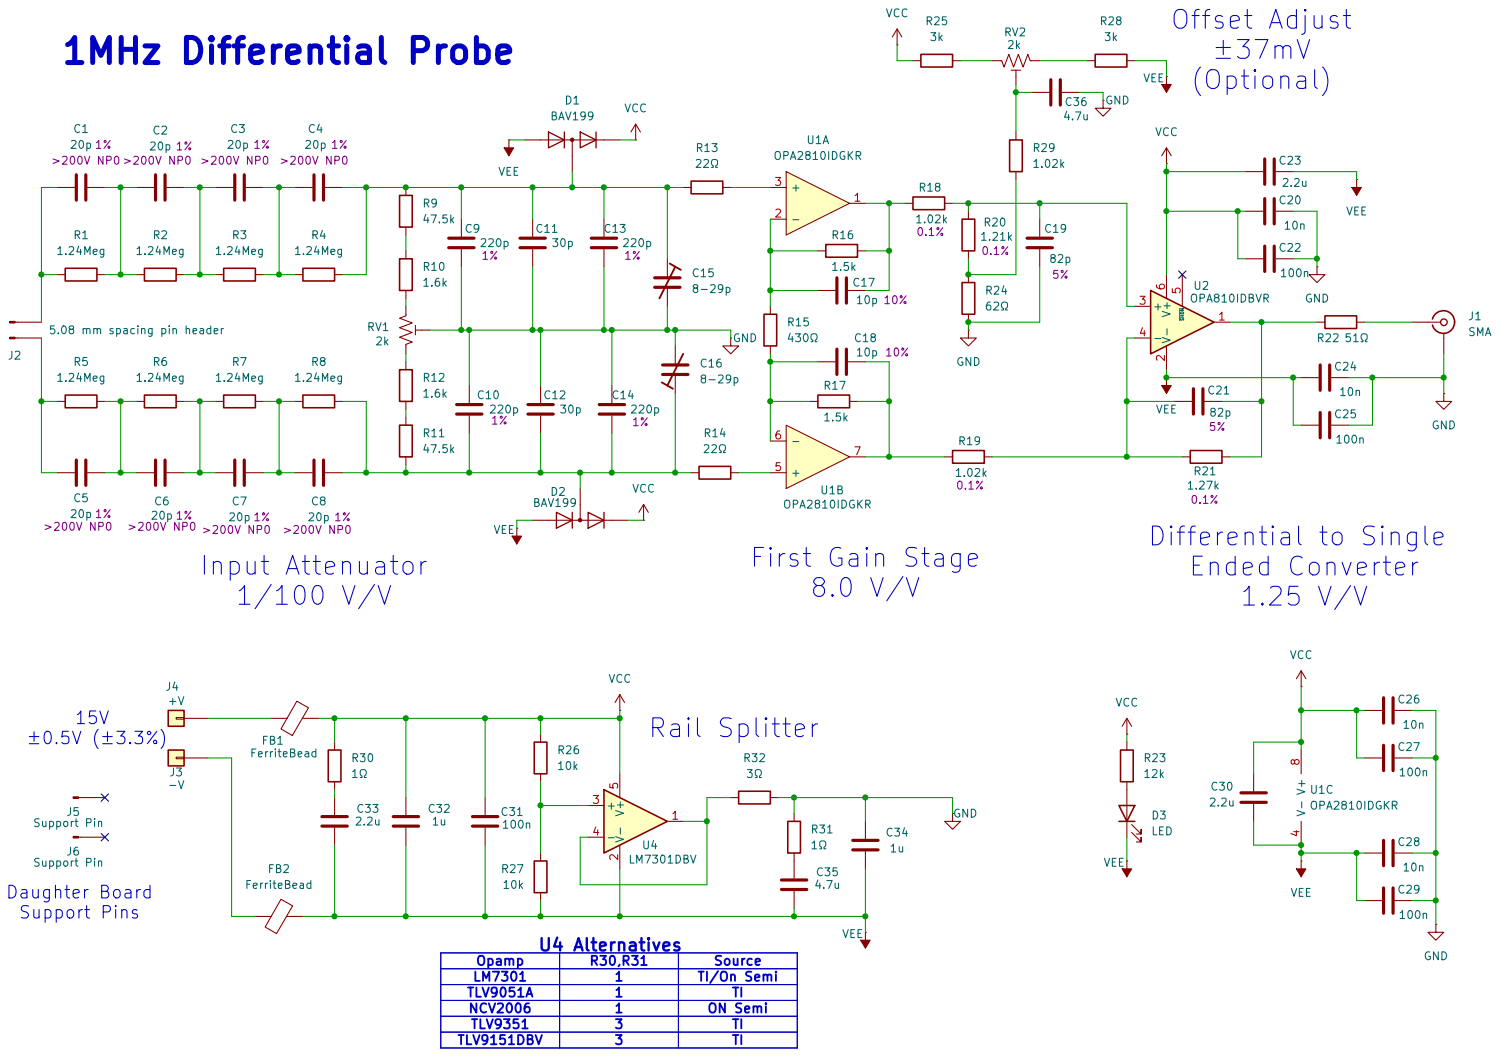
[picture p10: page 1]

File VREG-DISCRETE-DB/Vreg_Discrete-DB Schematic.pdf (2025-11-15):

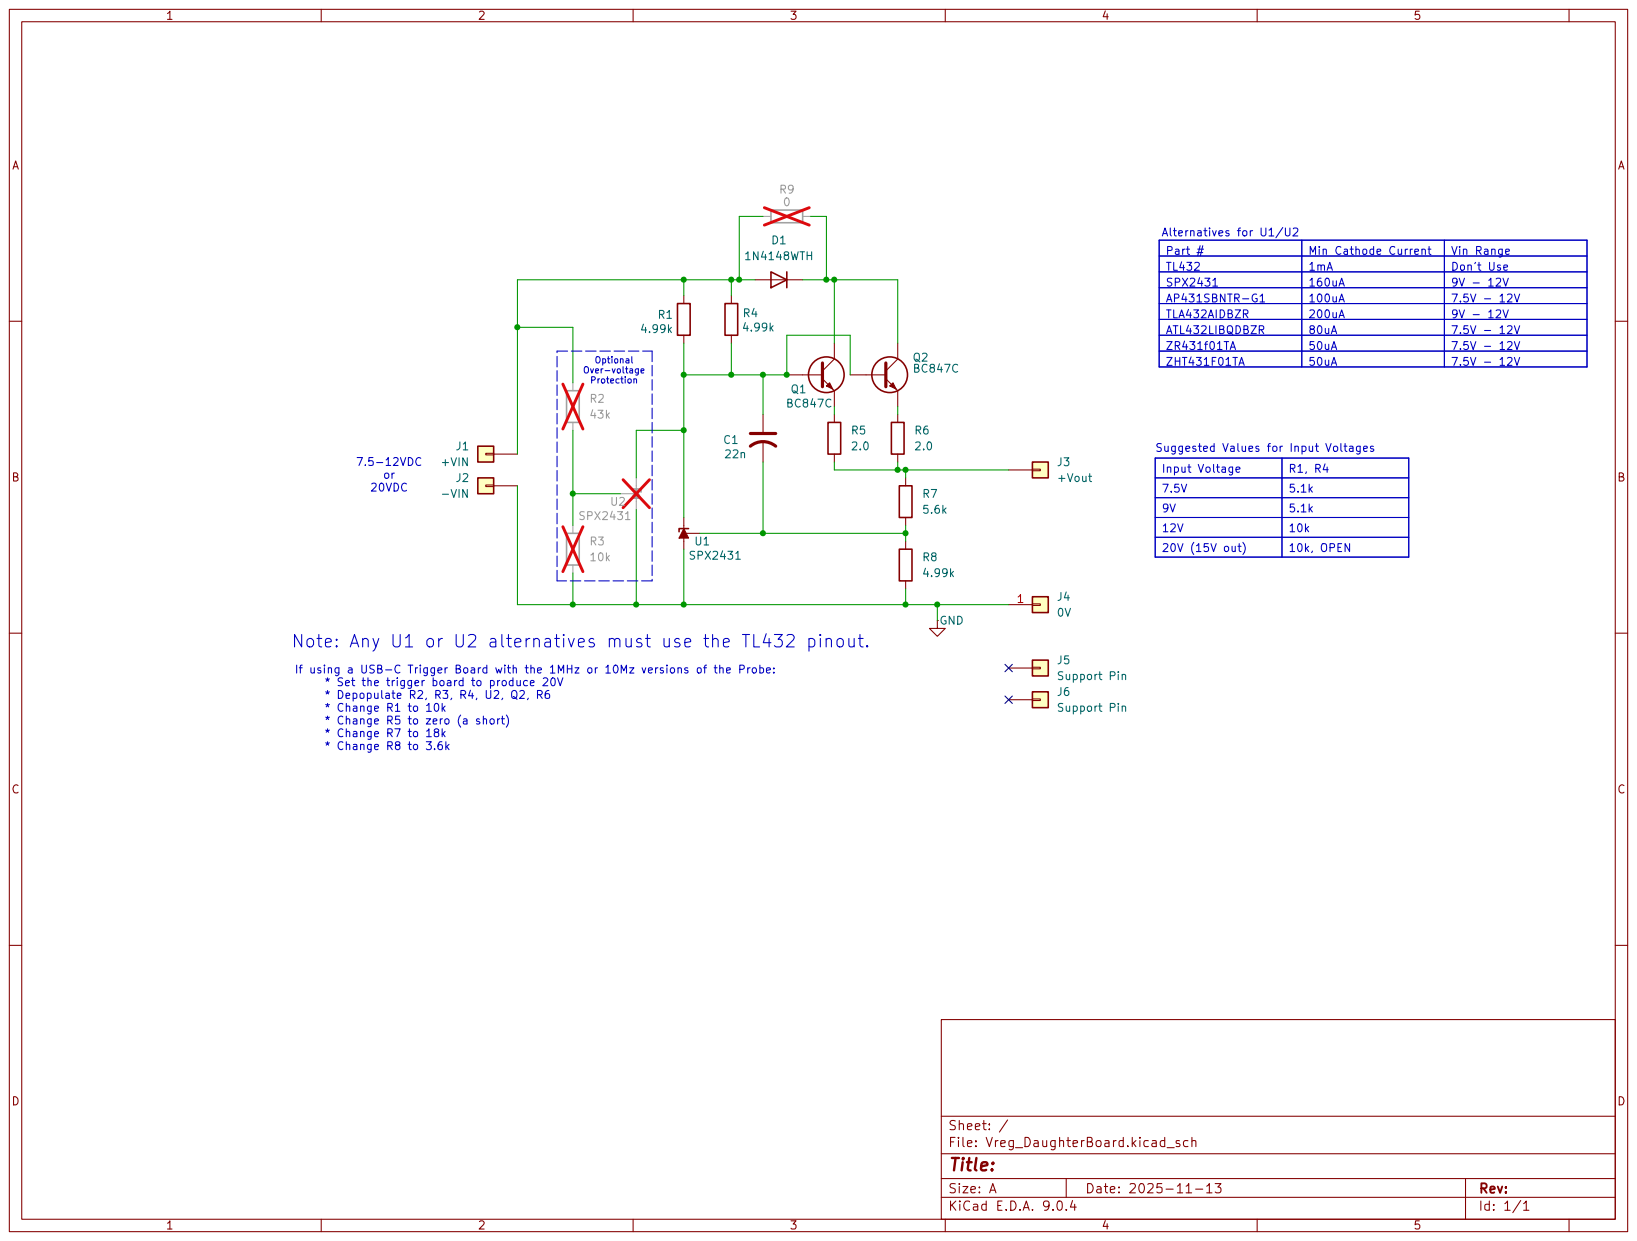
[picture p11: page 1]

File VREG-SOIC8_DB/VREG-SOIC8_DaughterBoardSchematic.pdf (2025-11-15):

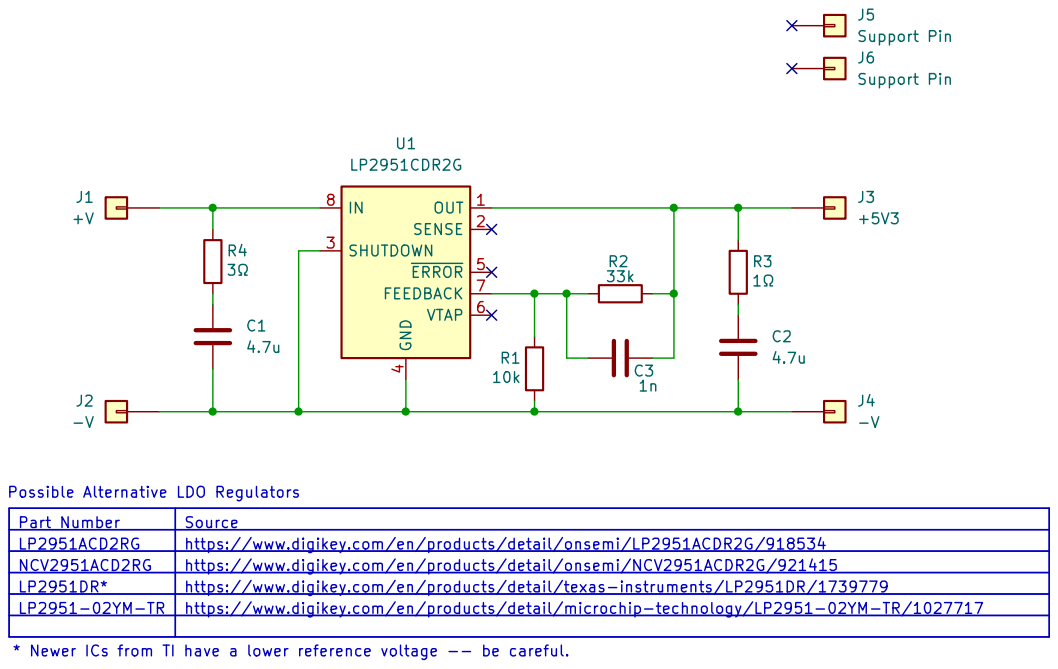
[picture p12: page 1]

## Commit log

2025-11-15 Add files via upload
    Here are the files required to 3D print the two halves of the diff probe.
    [DiffProbeSlim-ProbeHousing.step, DiffProbeSlim-ProbeHousing.stl, DiffProbeSlim-ProbeLid.step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]
2025-11-15 Add files via upload
    This is the information for the SOIC-8 Daughter Board
    [VREG-SOIC8_DaughterBoard.kicad_pcb_bom.csv, VREG-SOIC8_DaughterBoard.kicad_pcb_positions.csv]
2025-11-15 Add files via upload
    This is the discrete version of the power supply. It can be populated in several versions. With over-voltage protection, without, and a simple version for the 20V output for the 1 and 10MHz probes.
    [Vreg_DaughterBoard.kicad_pcb_bom.csv, Vreg_DaughterBoard.kicad_pcb_positions.csv]
2025-11-15 Add project overview and details to README
    Added project description and details about the differential probe versions and resources.
2025-11-16 Update README with detailed probe version info
    Clarified descriptions of probe versions and power options.
2025-11-16 Include specifications in README.md
    Added specifications for the differential probe.
2025-11-17 Revise specifications for 100MHz differential probe
    Updated specifications for the 100MHz probe, including changes to voltage ranges and noise levels.
